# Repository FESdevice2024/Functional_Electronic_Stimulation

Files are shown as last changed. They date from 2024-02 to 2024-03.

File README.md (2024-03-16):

This repository holds the contents discussed in the research discussed in:  

Samuel Lobert, Anik Baul and Dr. Ahmed Abdelgawad, “Replication and Advancement of a Functional Electronic Stimulation Device: A Practical Guide,” 3rd IEEE International Conference on Computing and Machine Intelligence (ICMI 2024), Mount Pleasant, MI, USA, April 2024. 

These files are presented for use in recreating and advancing the discussed PCB and circuit. The authors hope additional research will be conducted which improves the overall efficiency and effectiveness of FES devices for medical applications. The authors only ask that our work be properly cited in the case that any of our findings or files are used in future FES or similar applications. Note, many PCB designs were attempted for this research and the research team decided to include multiple of these designs in this repository for future research to build upon.  

If there are an yquestions about the material in this repository, or any questions about how the research team may be able to help in future research, please contact Samuel Lobert at lober1sc@cmich.edu or lobertsa@msu.edu .The research team thanks you for your interest in our work.

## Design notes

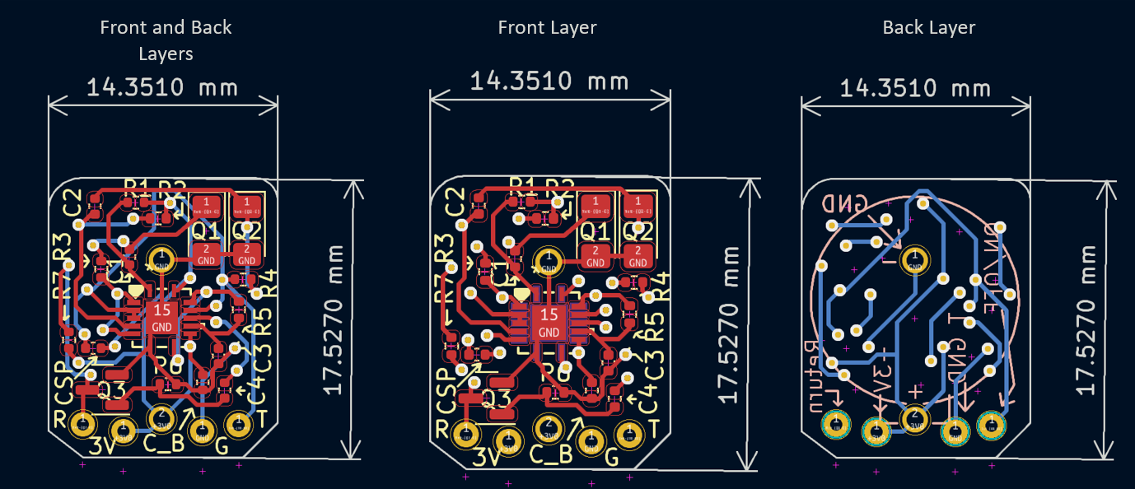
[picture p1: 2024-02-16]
FES Paper Images/Figure 4 Layout Images.png

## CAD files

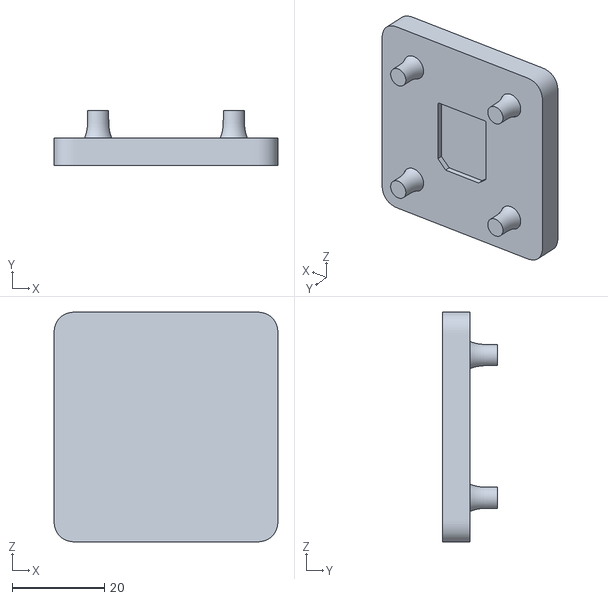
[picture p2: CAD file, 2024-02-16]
CAD Files 3D Printing Assembly Parts/FES Assembly Fixture With Stencil Mount.stl
48.6 x 12.0 x 49.9

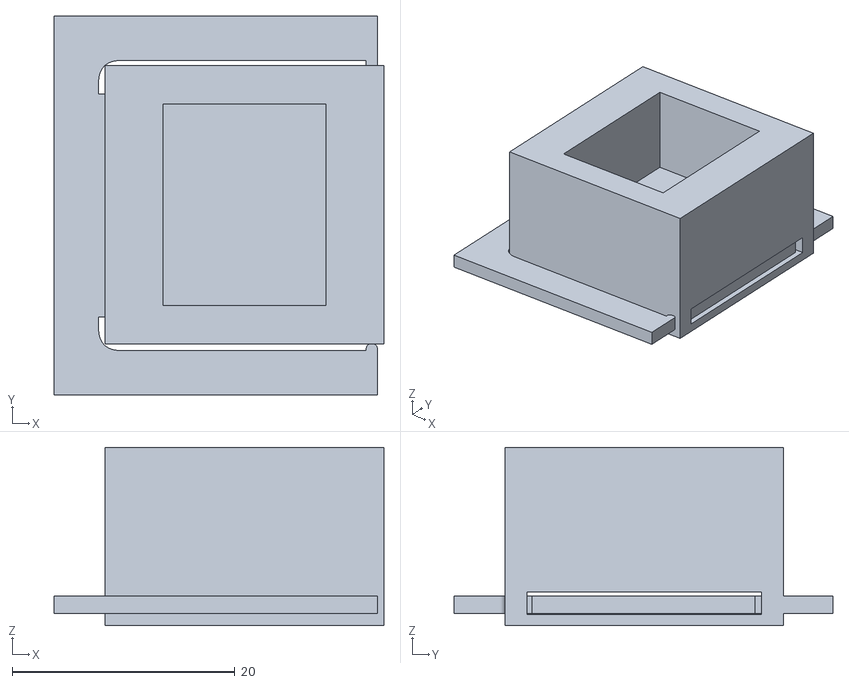
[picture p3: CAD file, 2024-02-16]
CAD Files 3D Printing Assembly Parts/RTV Curing Mold V1.stl
29.6 x 34.0 x 16.0

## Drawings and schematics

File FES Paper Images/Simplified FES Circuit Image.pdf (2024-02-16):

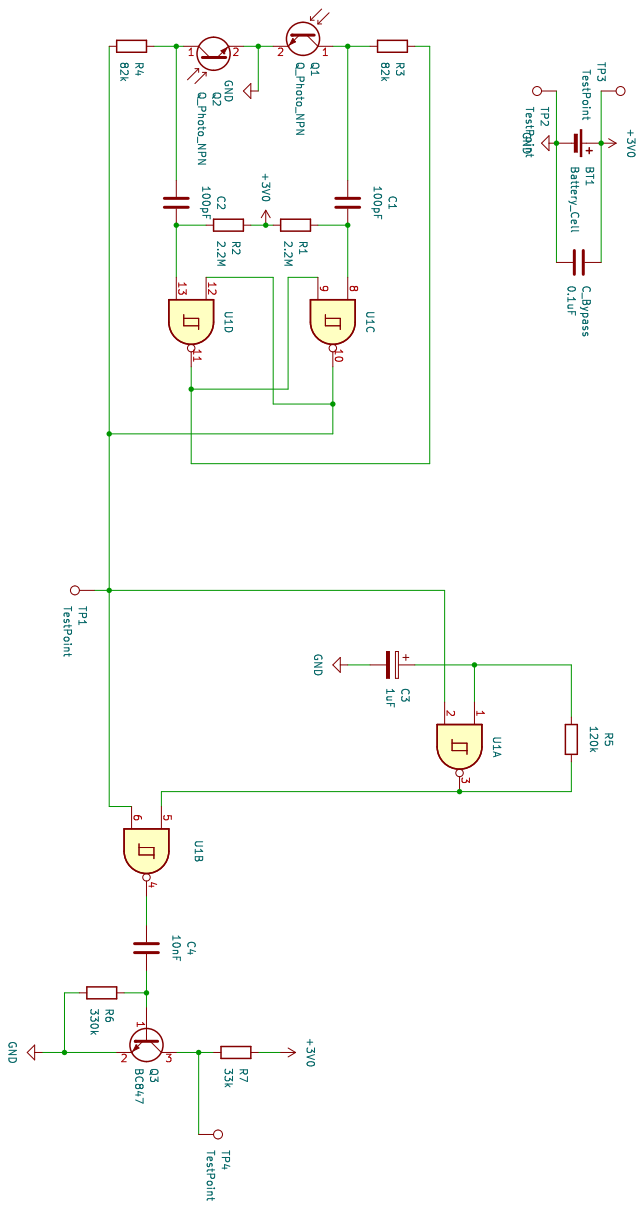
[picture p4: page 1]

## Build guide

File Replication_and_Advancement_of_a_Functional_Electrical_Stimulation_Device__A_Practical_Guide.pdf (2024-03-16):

# Replication and Advancement of a Functional Electrical Stimulation Device: A Practical Guide

Samuel Lobert
College of Science and Engineering Central Michigan University Mount Pleasant, MI 48858, USA lober1sc@cmich.edu

Anik Baul
College of Science and Engineering Central Michigan University Mount Pleasant, MI 48858, USA baul1a@cmich.edu

Ahmed Abdelgawad
College of Science and Engineering Central Michigan University Mount Pleasant, MI 48858, USA abdel1a@cmich.edu

Abstract—In medical rehabilitation, electric stimulation has always been significant. Though it is not a novel technique, Functional Electronic Stimulation (FES) requires improvement through ongoing research and development. This need for continuous improvement compounds when creating an implantable device. As implantable devices pose additional complex challenges, a thorough investigation is required to ensure the most efficient utilization of FES. Following Jarvis and Salmons’ original work, this paper examines the developments and difficulties involved in creating FES devices. We introduce improvements to the Jarvis and Salmons original circuit that will maximize power efficiency, prolong battery life, and increase durability. Our innovative technique developed a printable circuit board (PCB) that requires little interference during implantation and is powered by a single lithium-ion coin cell battery. By resolving concerns with PCB manufacture and functioning, our suggested improvements will advance the field of medical rehabilitation by providing useful information for the deployment of FES devices.
Index Terms—Functional Electronic Stimulation (FES), PCB, Medical Rehabilitation, Circuit Improvements, Circuit Design, Lithium-ion Coin Cell Battery, Power Efficiency, Battery Life
I. INTRODUCTION

The prospect of applying electrical stimulation in medical rehabilitation devices is one that has been around for many decades. One of the popular methods for attempting proper rehabilitation is with Functional Electronic Stimulation (FES) [1]. It was as early as 1967 that FES was defined as “electrical stimulation of muscle deprived of nervous control with a view of providing muscular contraction and producing a functionally useful movement” [2]. Although FES and FES devices are not novel approaches to medical rehabilitation, properly constructing an effective FES circuit and comprehensive device requires ongoing research. This problem becomes additionally challenging when an implantable device is required for studying the effects of FES in rehabilitation [3]. In 1991, Salmons and Jarvis proposed an implantable optical switching device [4] which has been used as the basis for many FES applications. This device laid the foundation for an effective FES model to be used by many separate parties to study the effects of applying FES through an implantable model.
As FES devices are used in the medical field, creating a proper device often requires interdisciplinary collaboration between the engineering and medical fields [5]. To the extent of our knowledge, implantable FES devices such as the Jarvis and Salmons device are not available to be commercially purchased. This requires those pursuing FES research to implement a custom circuit: a non-ideal challenge for medical experts without a technical background in circuit design and implementation [6]. In response to the need for a custom circuit, there is often a lengthy research and development phase by those tasked to create a functional FES device. This poses increased challenges for the original research team as the increased device lead time prolongs the time before the FES testing can be conducted [7].
Although this is true, due to the increase in available technology since Jarvis and Salmons published their original device, there are many areas for improvement which allow for an increase in operating life and durability. Furthermore, although Jarvis and Salmons discuss the functionality of their circuit, correctly replicating their device requires additional considerations and analysis. As the diversity in FES applications requires multiple different stimulation frequencies, analyzing the Jarvis and Salmons design allows their circuit to be adapted to fit the required specifications. It also allows for many advancements in circuit design and construction to be outlined to act as a guide for those who wish to take a similar approach to FES.
This paper acts as a practical guide for implementing the original Salmons and Jarvis device while building on their design. We updated the findings of Salmon’s circuit, produced the required material for implementation, and discussed the steps that are needed in order to recreate similar FES devices. We analyzed the original circuit to provide the equations for determining the correct resistance and capacitance to use to set the stimulation frequency and provide an updated device that offers increased implantable durability. Moreover, we also improved the battery life of the device so that it can run for a maximum time and allow for the possibility of being reused in multiple FES tests or used in FES tests of longer duration. As the device is powered by a single lithium-ion coin cell battery, the battery size needs to be reduced as much as possible to be the least invasive as possible when implanted. The proposed device also solves the problem that Jarvis and Salmons note of lifting of circuit tracks as the fabricated printable circuit board (PCB) effectively allows for the circuit to be implemented in a durable way. Although this problem is corrected through the use of easily fabricated PCB, the problem of effectively minimizing the PCB will be discussed.
Our main contributions are:
1) We alter the Jarvis and Salmons circuit topology to enable the clocking circuit only during stimulation. This leads to an increase in battery life.
2) We provide the circuit analysis required to set the stimulation frequency with the goal of adapting the device for a multitude of FES applications.
3) We provide a complete database of a bill of materials, PCB fabrication files, circuit simulations, and construction materials at an open source Github repository with the goal of reducing development time of similar FES devices in future applications. These files are available at https://github.com/FESdevice2024/ Functional Electronic Stimulation

II. RELATED WORKS
While more technologically advanced, programmable, models such as the one created by Callewaert and Puers [8] have been successfully demonstrated in FES applications, the repeated use of the Salmons and Jarvis device make it ideal for building on to use in future FES tests. Similarly, its simplicity lends itself to a low cost of construction as well as to minimizing the overall device footprint for implantation. Apart from size, battery life, and device cost, the frequency at which the device applies stimulation is also an important factor to designing FES devices. Defining an appropriate pulse frequency is a crucial parameter in the design stages and many researchers chose different ranges of frequency. The ability to understand how to change the frequency of the pulses produced by the FES device is of upmost importance due to the differing frequencies used in FES approaches. This is due to the fact that the target stimulation frequencies can vary depending on the application of the FES.
While the Salmons and Jarvis circuit generates a 10Hz pulse train, Nene et al. [9] used a 30 Hz pulse frequency for their FES device tests. Marsolais and Kobetic [10] demonstrated how functional neuromuscular stimulation (FNS) can be used outside of a controlled laboratory setting to help a patient who was previously unable to walk. They tested the effectiveness of FES devices of frequencies between 20 Hz and 50Hz. Similarly, M.R. Popovic and his colleagues [11] found that a minimum frequency of around 16-20 Hz was needed to effectively induce muscular contractions when the target of FES is on the muscle structure.
Although many of these FES applications use stimulation frequencies in the range of 20-50 Hz, other applications for FES focused on the use of frequencies outside this range. Liu and Grumbles [12] used a 1Hz frequency which showed promising results in improving axon regeneration. On the other hand, Song et al. [13] propose an implantable FES device that provided the ability to apply stimulation in a range of frequencies between 300 and 5000 Hz. As the frequency of stimulation pulses that FES devices are required to deliver changes depending on the application, it is important to analyze the method for determining the stimulation frequency of the proposed device.

III. TECHNICAL DETAILS

The original circuit designed by Salmons and Jarvis has three main subcircuits. Fig. 1 describes the original Jarvis and Salmons circuit which shows the connection of the Schmitt Trigger NAND oscillator to the 3V source. The three main parts of the circuit include the cross coupled NAND SR latch, a Schmitt Trigger oscillator to create a clock signal, and the stimulator to apply a 200µs duration pulse. When a pulse of light from a 300-lumen flashlight is applied to the SR latch’s phototransistors, the SR latch toggles between an on and off state as Jarvis and Salmons describe. This output is connected to another NAND gate along with a resistor and capacitor to create a Schmitt Trigger Inverting oscillator to control the frequency of the applied pulses. The output of this NAND gate is connected to an RC differentiator circuit and a bipolar junction transistor (BJT) in order to create a pulse that is approximately 200µs in duration. As the BJT allows current to flow from the collector to the emitter during each pulse, the output voltage is created across the pull-up resistor and allows a pulse to be delivered to the targeted tissue.

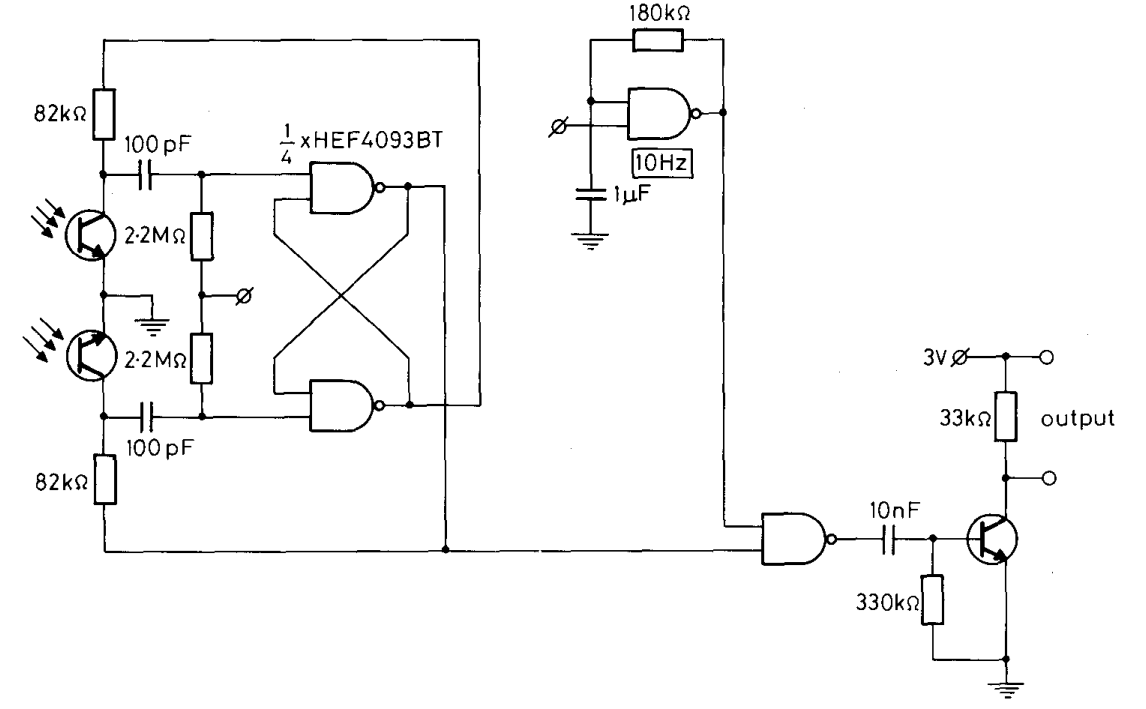
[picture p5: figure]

Fig. 1. Original circuit designed by Salmons and Jarvis [4]

In the proposed circuit, these core components remain unchanged. Although this is true, the parts list quoted by Salmons and Jarvis contains many components that have been discontinued by their manufacturer. New versions of the discontinued components were selected by comparing datasheets of the discontinued components with those for actively produced components. The benefit of using this circuit is that each of these three subcircuits can be created using a single Quad 2-input NAND gate Schmitt trigger IC. Salmons and Jarvis originally used the HEF4093BT Quad 2-input NAND gate Schmitt trigger, but this does not present the ideal IC due to the range of operating voltage as well as the size. Although the HEF4093BT is still in production, its recommended supply voltage (VDD) is listed by the manufacturer as 3-15V. As the FES device is powered by a 3V coin cell, the standard operating voltage represents the very minimum value recommended for operation. This poses a problem as any induced noise or drop in battery voltage may result in unideal operating conditions for the IC. Similarly, the package size of the HEF4093BT is 8.75 mm by 6.2 mm at its largest tolerance. In the effort to reduce the implants size and reduce invasiveness of the implant, a smaller IC package size is ideal. Due to this, the SN74AHC132 poses an ideal solution as it is available in a quad flat no-lead (QFN) package and has an operating range of 2 – 5.5 V for supply voltage. With the SN74AHC132’s QFN package, the layout is reduced to a size of 4.8-4.8 mm which represents a major size reduction from the HEF4093BT.
Another important aspect to note is that the SN74AHC132 recommends that a bypass capacitor should be implemented in order to prevent power disturbance. Adding a bypass capacitor is good practice as it provides system stability from and fluctuations in the source voltage [14], but Salmons and Jarvis do not mention any use of a bypass capacitor. Following the recommendation of the SN74HC’s datasheet, a 0.1uF capacitor was implemented across the source voltage.
Observing Jarvis and Salmons method of implementing the NAND gate Schmitt Trigger oscillator shows that the NAND gate provides the use of an enabling input. This is because the NAND gate Schmitt Trigger oscillator is an extension to the more simple inverting Schmitt Trigger oscillator. The NAND gate Schmitt Trigger oscillator provides the same functionality as if the inverting Schmitt Trigger is used, but the second input on the NAND gate allows the clock signal to be enabled and disabled depending on the state of the second input. In connecting this enabling input to the positive source voltage as done by Salmons and Jarvis, the device provides a clock signal as long as it is connected to the battery. Since FES devices are typically used for one-hour intervals per day [1], the battery continuously produces a clock signal by continuously charging the clocking capacitor for 23 hours of unrequired time.
The solution to this lies in connecting the enable input on the Schmitt Trigger Oscillator to the enabling output of the SR latch. A schematic of the proposed circuit after making this change is shown in Fig. 2. This connects the enabling input on the clock to the enabling input of the stimulator meaning that the clocking signal is only produced when stimulation is required. In turn, this reduces the time power consumed by the clocking circuit from 24 hours a day to between 1 to 2 hours a day depending on stimulation requirements.
Using (1), the frequency produced by the clock can be calculated. In the Schmitt Trigger oscillator, the capacitor continuously charges and discharges between the positive threshold voltage and the negative threshold voltage of the SN74AHC132 due to the hysteresis of the Schmitt trigger.

f =

1
RC · ln( VDD−VN
VDD−VP

×

VN
VP

)

(1)

Where VN represents the negative voltage threshold of the Schmitt trigger NAND gate, VP represents the positive threshold of the NAND gate, and VDD represents the source voltage.
Fig. 3 represents the waveform depicting the charging cycle of the Schmitt Trigger oscillators capacitor. As the battery discharges during the charging of the capacitor then the

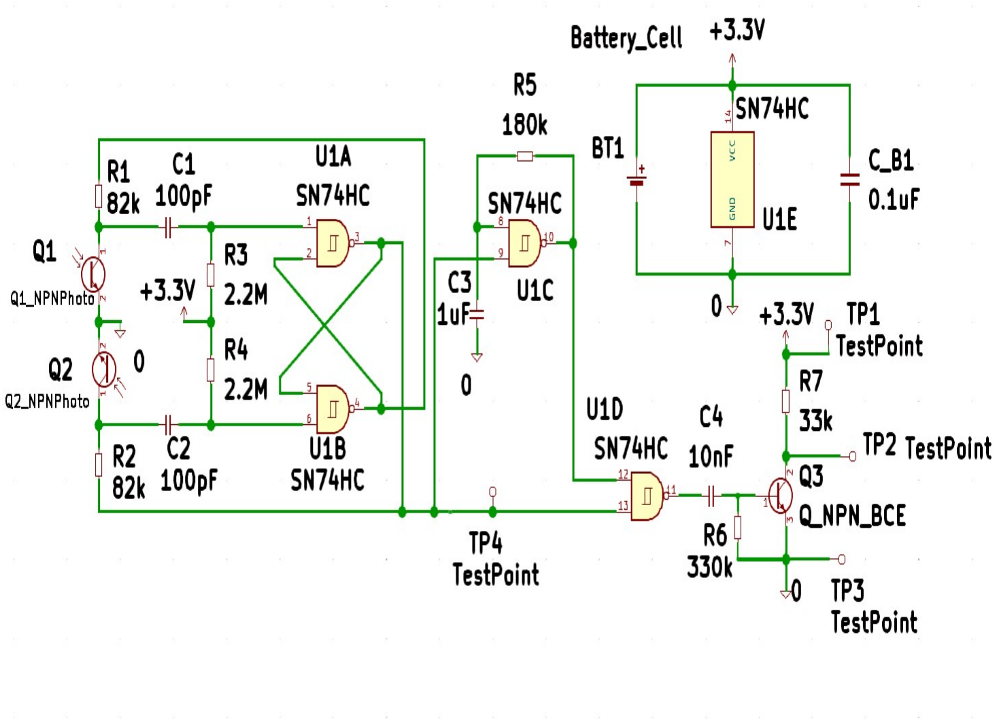
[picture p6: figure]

Fig. 2. An updated circuit design

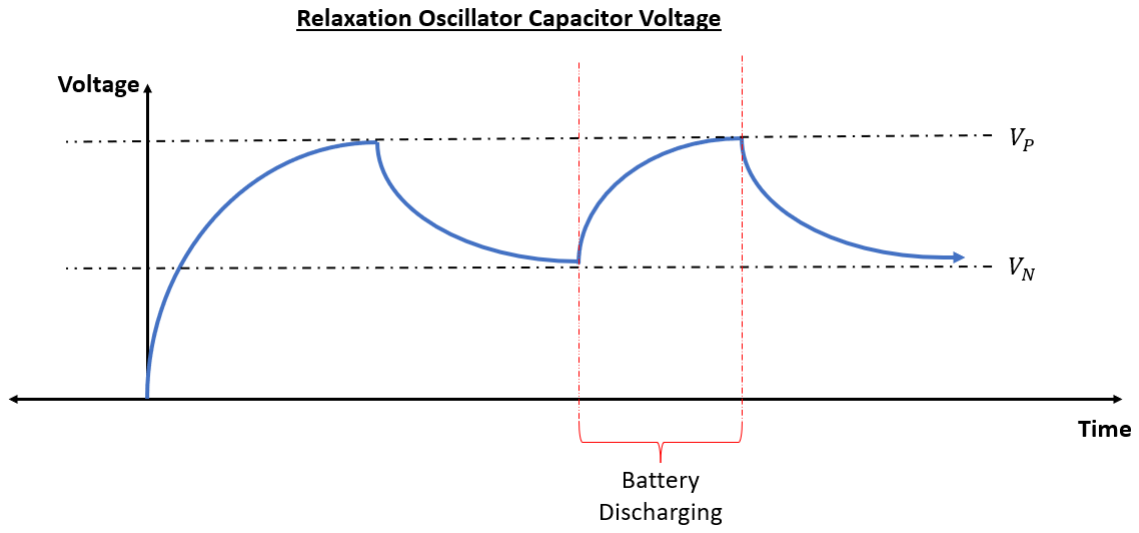
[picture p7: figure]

Fig. 3. Charging cycle of the Schmitt Trigger oscillator’s capacitor

equation for the voltage over a charging capacitor can be accessed using equation (2) to calculate the time of one charge. Here,
VC (t) = VS
1 − e

− t

RC
(2)

VC (t) & VS are voltage across the capacitor & the source voltage or the initial voltage supplied to the capacitor. R denotes the resistance in the circuit & C is the capacitance of capacitor. As the resistance value for the Schmitt Trigger oscillator is known from (1), the average current can be found by integrating the charging voltage divided by the resistance from the time to voltage VN to the time to voltage VP . This calculation produces the number of coulombs consumed for each charge of the capacitor which is helpful as the 3V coin batteries are labeled by their total charge in milliamp hours (mAh). Multiplying this result by the frequency and converting it to hours gives the number of mAh the clock consumes per hour operation. This calculation can also be conducted for the simulator and the SR latch. The sum of this value provides the total number of mAh consumed during an hour of operation which can then be used to calculate the number of hours of operation that can be expected based on the chosen number of hours operating a day and the chosen battery size.

IV. RESULTS
The proposed device was created using a 2-layer PCB and the layout diagram is depicted in Fig. 4. A 40-gauge siliconecoated stainless-steel medical wire (Cooner Wire Company AS-631) was used for connecting the device to the stimulating electrodes as well as running through a small port in the body to test whether the device is in the on or off state. The total cost of the circuit components, PCB, and approximately 12 inches of AS-631 that were used to create a device is $29.61. In order to implant the devices, each PCB is coated in the DOWSIL 3140 room-temperature vulcanizing (RTV) Silicone coating. A 90-milliliter tube of this coating was available to be purchased for around $40.00.


Fig. 4. Layout Design of the proposed device

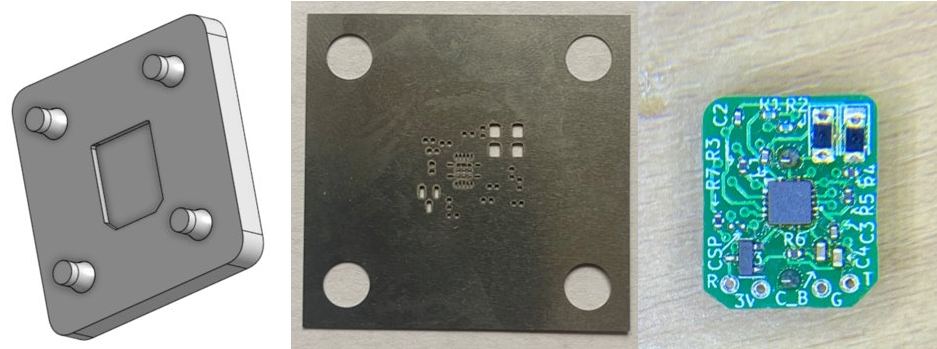
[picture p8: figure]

Fig. 5. Fabrication and Assembly Materials for the proposed device

Due to its simplicity and cost effectiveness, the two-layer board was chosen over a multilayered board. When attempting to create a 4-layer design, the increase in the number of via placements restricted the design from being minimized by an impactful amount. The design in Fig. 4 was created using the free version of the KiCad EDA 7.0 layout design environment which allowed the needed files to be created for fabrication. The design files can then be submitted to a chosen fabricator for board construction. The proposed design was fabricated by the JLCPCB: PCB Prototype & PCB Fabrication Manufacturer. All of the files used to fabricate the device are located in the provided GitHub repository to recreate the device or alter the proposed design for a desired application. After fabrication, many PCB fabricators offer the ability to populate the design with the required components, but in order to save costs, this step was done by the design team. The files for the 3D printable PCB mount, solder paste stencil used in the component fabrication process and the populated PCB of the proposed design are depicted in Fig. 5.
The datasheet of the SN74AHC132 lists the positive and negative thresholds at a 3V supply voltage, but only the maximum and minimum values are shown. In order to determine the frequency, these values were measured by measuring the voltage over the clock’s capacitor. Fig. 6 depicts these results and shows that the Vp value is 1.185V and the VN value

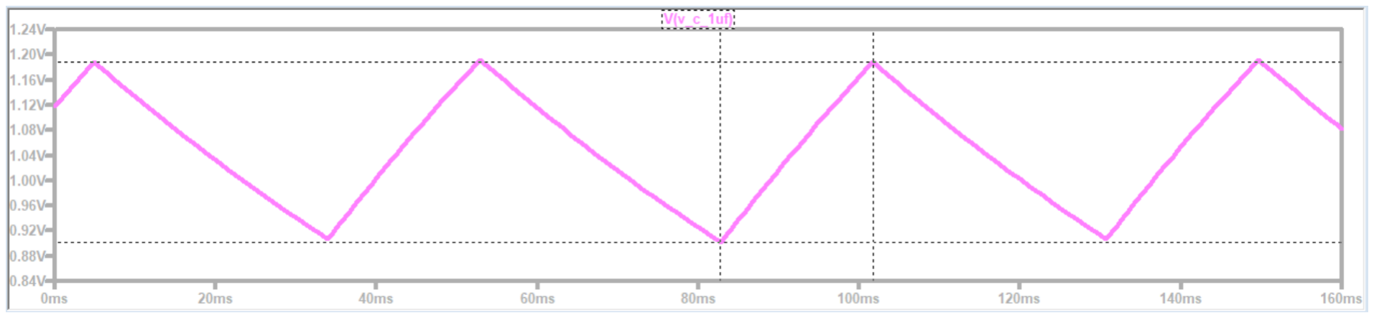
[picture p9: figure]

Fig. 6. Simulated clock capacitor voltage to determine Schmitt Trigger threshold voltages

is 905.817mV when powered by a 3V source, the system produces a simulated frequency of 20.24 Hz. Fig. 7 depicts the resulting pulsing frequency used when a 120 kOhm resistor and a 1 µF capacitor are used. This led to an output stimulation frequency of 18.87 Hz. This results in a percent error of 6.77% between the theoretical frequency and the measured frequency. Similarly, Fig. 8 depicts the resultant pulse that is to be used for stimulation. As Salmons originally notes, this pulse is close to 200µs in duration with the proposed duration of a pulse 90% of the maximum pulse voltage lasting for 218.0µs.

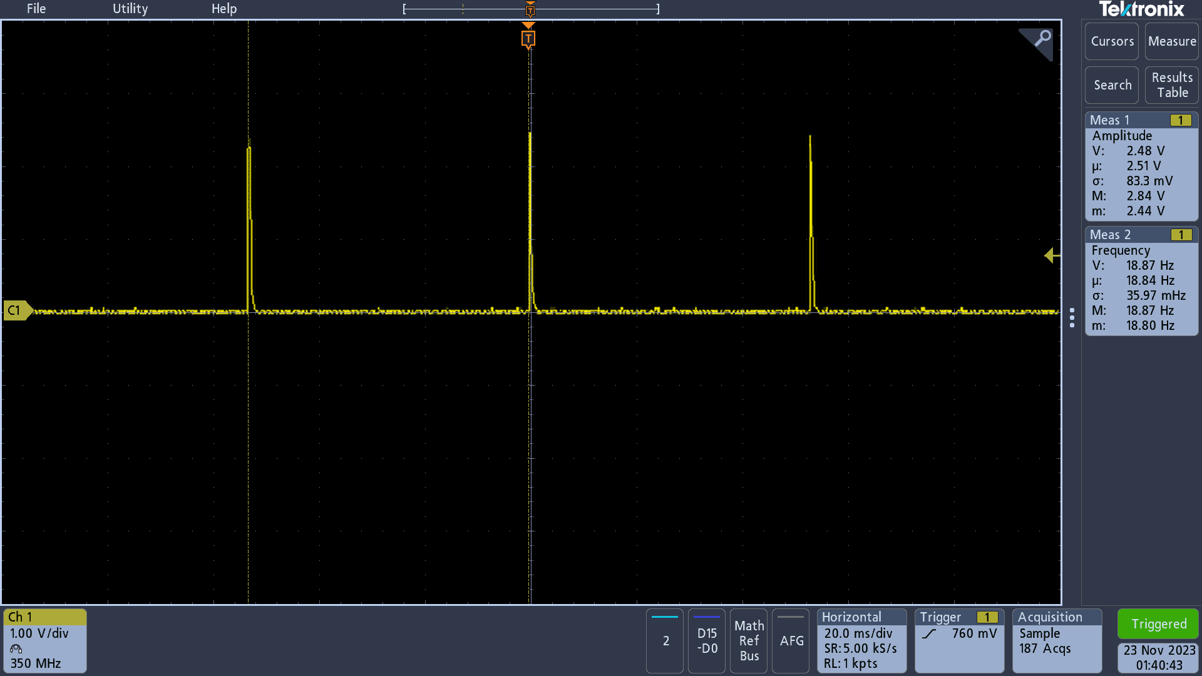
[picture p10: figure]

Fig. 7. Resulting Pulsing frequency

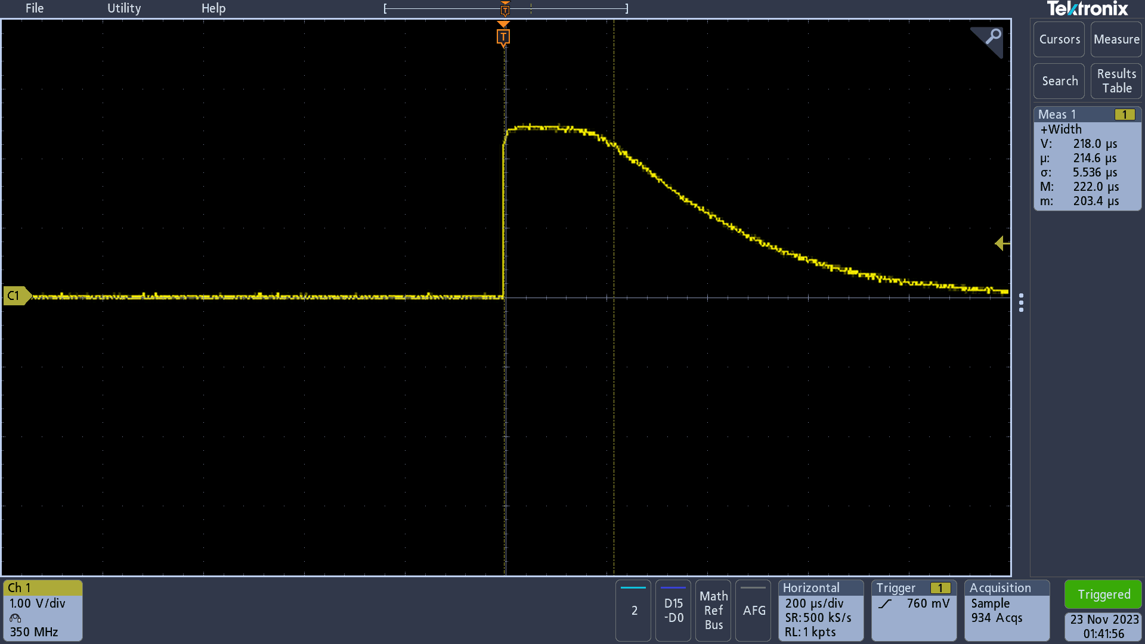
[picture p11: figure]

Fig. 8. Pulse Width

V. CONCLUSION
To summarize, this paper explains improvements in the design of FES devices by utilizing knowledge from the foundational work of Jarvis and Salmons. With the files provided
in | the | FESdevice2024/Functional Electronic Stimulation
GitHub repository, the proposed design can be implemented into future FES applications and decrease the lead time required to create an implantable device. Additionally, the files allow for future advancements and alterations to be added to the proposed design to increase the functionality of FES implants to a larger range of applications than the proposed device has. We have significantly improved performance and durability by modernizing Salmons’ circuit architecture. The proposed device will be used in FES research where the device will supply pulses for two hours a day for a duration of seven continuous weeks. In all cases where the FES device is not required to supply a continuous pulse train throughout an entire day, operating the Schmitt Trigger oscillator for the entire day causes an unnecessary use of power which decreases the battery life of the device. We improved the battery life of the device by adding the functionality to enable the clocking circuit and reduced power consumption. These are both critical for implanted devices. We overcame issues found in previous models by effectively implementing an improved hardware arrangement. These contributions lead to a practical guide for implementing a functional FES device to be created.

VI. ACKNOWLEDGMENT
We are grateful to Dr. Adam Mock, Austin Kane, and David Stanley for their valuable suggestions and help on many occasions throughout the process of building the FES devices.

REFERENCES

[1] Ilya Demchenko, Naaz Desai, Stephanie N Iwasa, Fatemeh Gholamali Nezhad, Jose Zariffa, Sidney H Kennedy, Nicholas O Rule, ´ Jeffrey F Cohn, Milos R Popovic, Benoit H Mulsant, et al. Manipulating facial musculature with functional electrical stimulation as an intervention for major depressive disorder: a focused search of literature for a proposal. Journal of NeuroEngineering and Rehabilitation, 20(1):64, 2023.
[2] Matthew Yough. Advancing medical technology for motor impairment rehabilitation: Tools, protocols, and devices. 2023.
[3] Kenneth B Baker, Ela B Plow, Sean Nagel, Anson B Rosenfeldt, Raghavan Gopalakrishnan, Cynthia Clark, Alexandria Wyant, Madeleine Schroedel, John Ozinga IV, Sara Davidson, et al. Cerebellar deep brain stimulation for chronic post-stroke motor rehabilitation: a phase I trial. Nature Medicine, 29(9):2366–2374, 2023.
[4] S Salmons and JC Jarvis. Simple optical switch for implantable devices. Medical and Biological Engineering and Computing, 29:554–556, 1991.
[5] EJ Gann, VJ Block, and DD Allen. A novel functional electrical stimulation device plus telerehabilitation improves walking in people with multiple sclerosis: A case series. Multiple Sclerosis and Related Disorders, 73:104648, 2023.
[6] Gustavo Balbinot, Guijin Li, Cindy Gauthier, Kristin E Musselman, Sukhvinder Kalsi-Ryan, and Jose Zariffa. Functional electrical stimulation therapy for upper extremity rehabilitation following spinal cord injury: a pilot study. Spinal Cord Series and Cases, 9(1):11, 2023.
[7] Finn Rapp, Constantin Wiesener, Markus Valtin, and Thomas Schauer. Combining voltage and current control for efficient electrical stimulation. In 2023 International Interdisciplinary PhD Workshop (IIPhDW), pages 1–4. IEEE, 2023.
[8] Callewaert L, Puers B, Sansen W, Jarvis JC, Salmons S. Programmable implantable device for investigating the adaptive response of skeletal muscle to chronic electrical stimulation. Med Biol Eng Comput. 1991 Sep;29(5):548-53. doi: 10.1007/BF02442329. PMID: 1817220.
[9] AV Nene, HJ Hermens, and G Zilvold. Paraplegic locomotion: a review. []Spinal cord, 34(9):507–524, 1996.
[10] EB Marsolais and RUDI KOBETIC. Functional walking in paralyzed patients by means of electrical stimulation. Clinical Orthopaedics and Related Research®, 175:30–36, 1983.
[11] Milos R Popovic, Thierry Keller, IPI Papas, Volker Dietz, and Manfred Morari. Surface-stimulation technology for grasping and walking neuroprostheses. IEEE Engineering in Medicine and Biology Magazine, 20(1):82–93, 2001.
[12] Yang Liu, Robert M Grumbles, and Christine K Thomas. Electrical stimulation of embryonic neurons for 1 hour improves axon regeneration and the number of reinnervated muscles that function. Journal of Neuropathology & Experimental Neurology, 72(7):697–707, 2013.
[13] K. -I. Song, A. Shon, J. -U. Chu, K. Choi, D. Hwang and I. Youn, ”An implantable wireless system for muscle afferent recording from the sciatic nerve during functional electrical stimulation,” 2013 35th Annual International Conference of the IEEE Engineering in Medicine and Biology Society (EMBC), Osaka, Japan, 2013, pp. 3610-3613, doi: 10.1109/EMBC.2013.6610324.
[14] W. B. Kuhn and A. D. Fund, ”Power supply bypass capacitors—Myths and realities,” 2015 IEEE Radio Frequency Integrated Circuits Symposium (RFIC), Phoenix, AZ, USA, 2015, pp. 405-408, doi: 10.1109/RFIC.2015.7337791.

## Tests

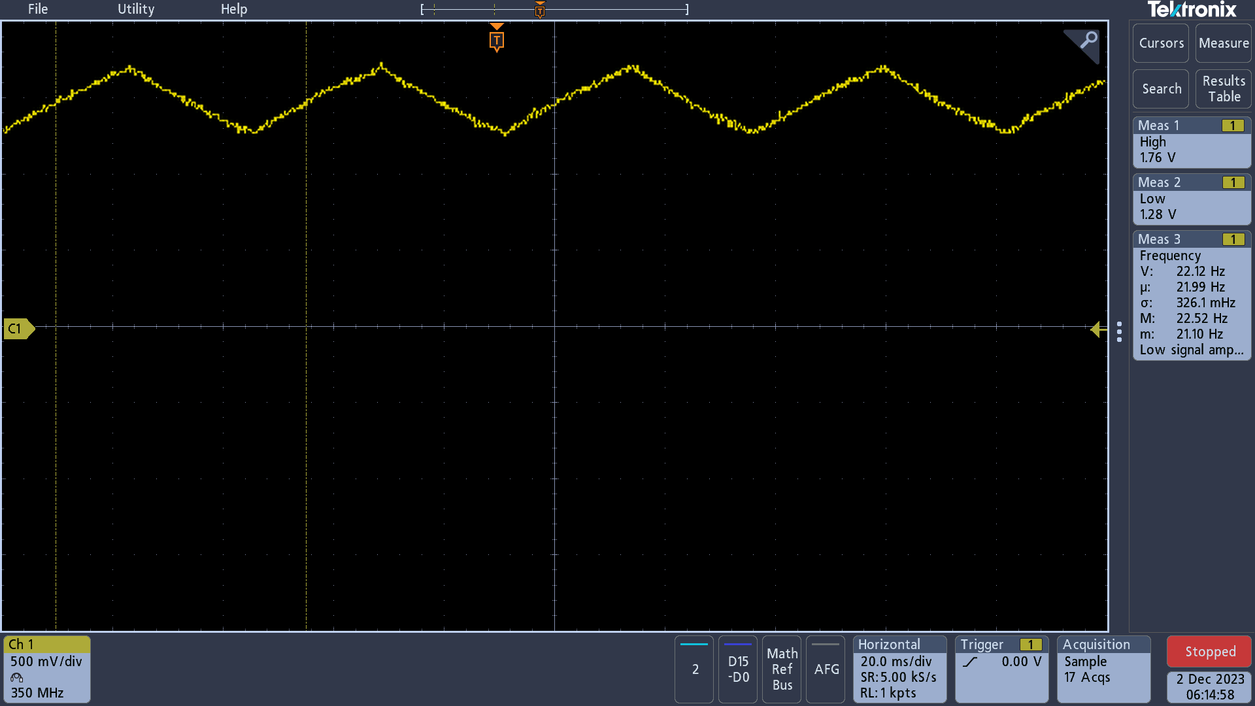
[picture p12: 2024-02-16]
FES Oscilloscope Images From Testing/Untitled Images/tek00001.png

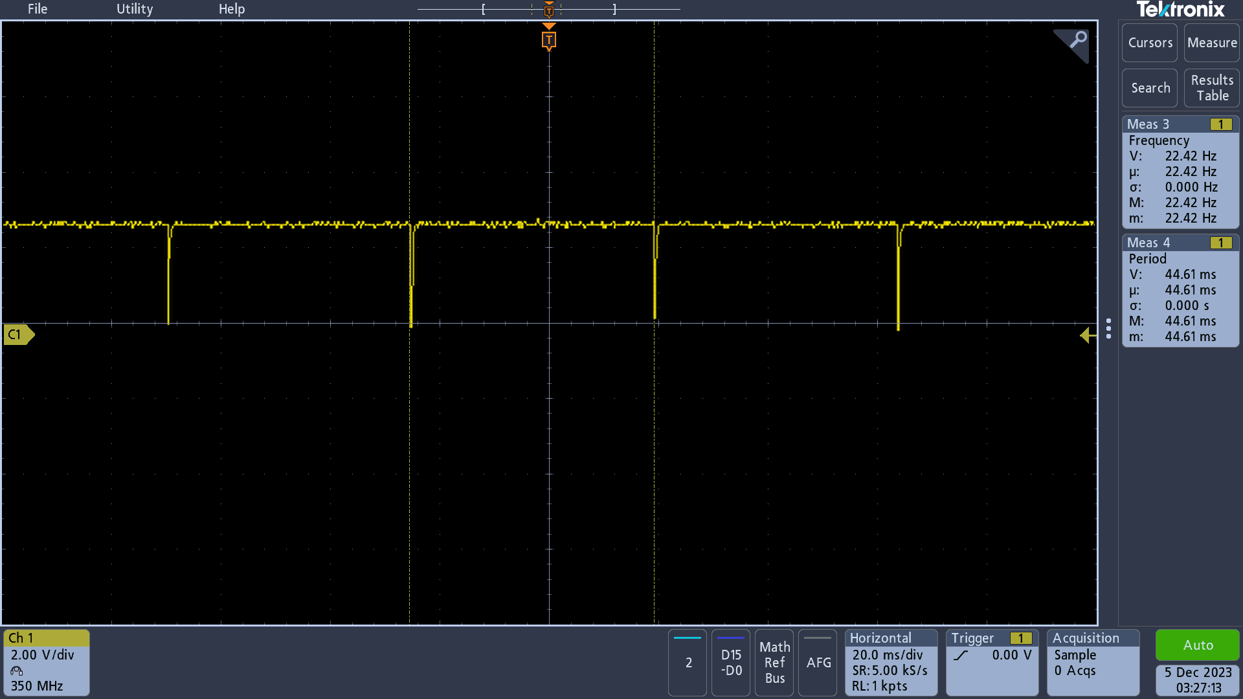
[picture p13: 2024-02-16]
FES Oscilloscope Images From Testing/Untitled Images/tek00020.png

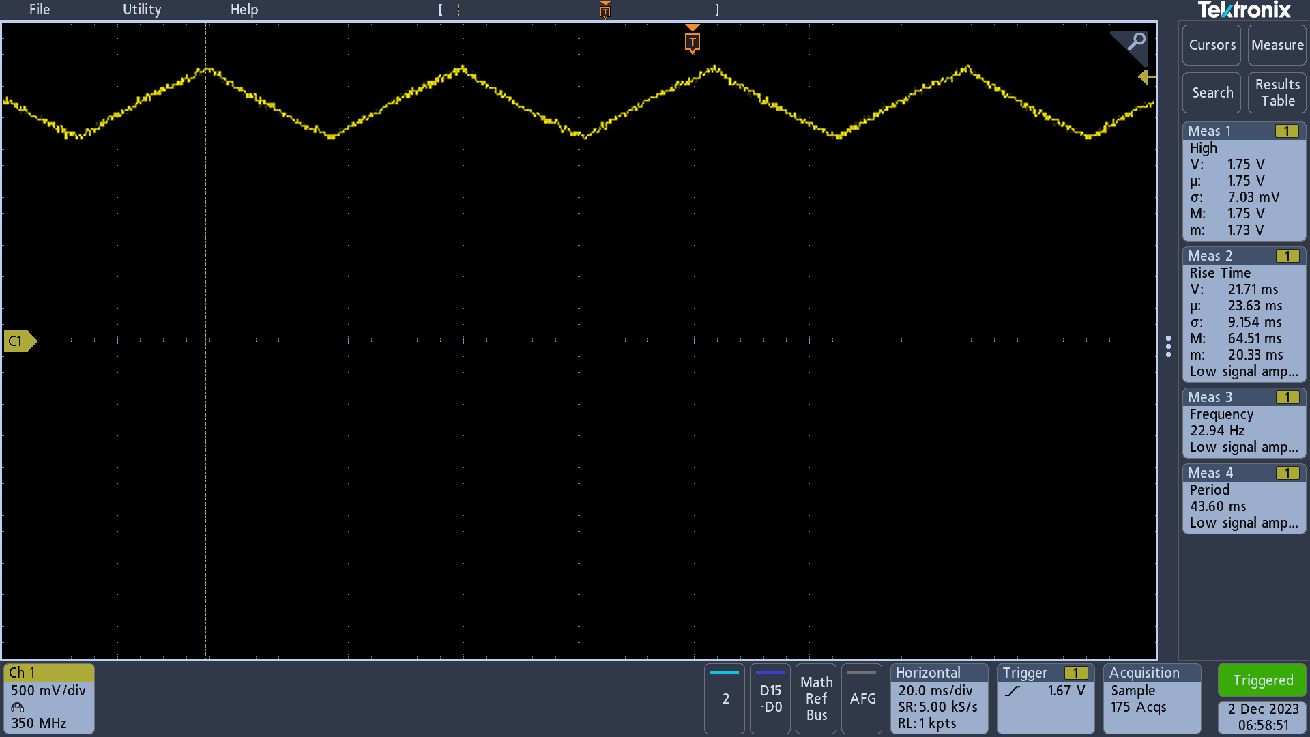
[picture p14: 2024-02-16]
FES Oscilloscope Images From Testing/Untitled Images/tek00016.png

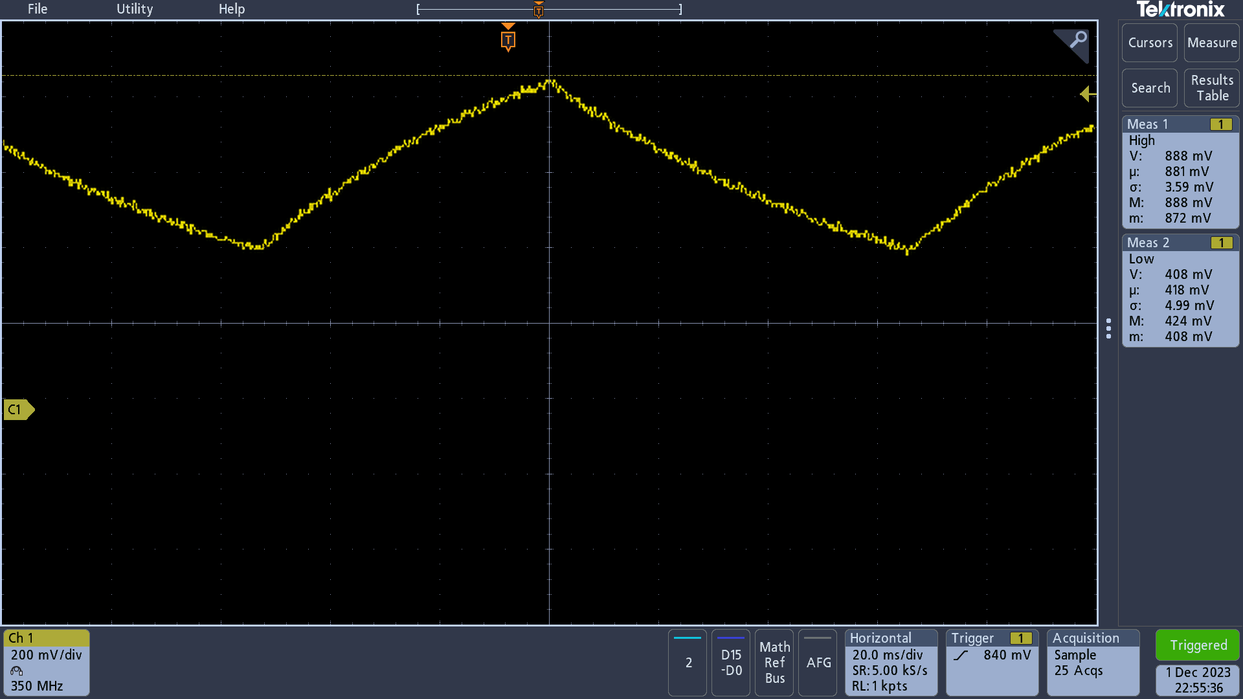
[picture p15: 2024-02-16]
FES Oscilloscope Images From Testing/clock6.png

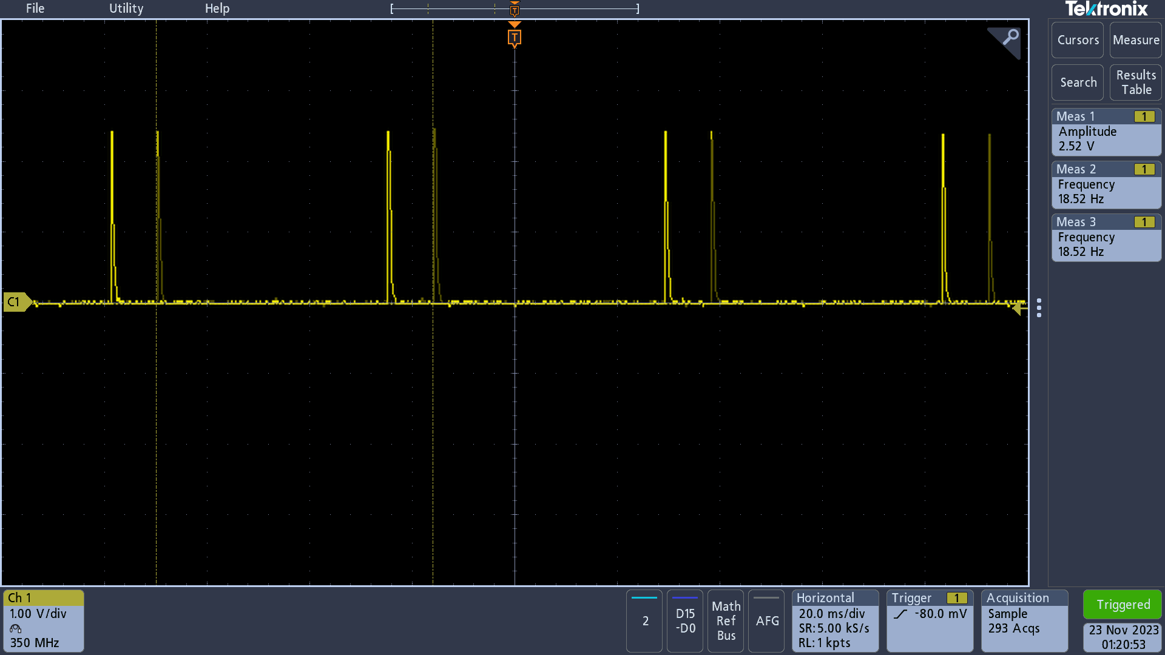
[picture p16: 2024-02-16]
FES Oscilloscope Images From Testing/tek00000.png
